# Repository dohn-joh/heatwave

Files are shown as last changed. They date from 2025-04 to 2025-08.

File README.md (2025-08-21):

cover_photo

***

Heatwave is a 36-key wireless, curved alpha stagger keyboard with integrated lever keycaps.

[PCB](pcb)

[Case files](case)

[swell keycaps](https://github.com/dohn-joh/swell-keycaps)

[ZMK Module](https://github.com/dohn-joh/heatwave-zmk-module)

[video](https://vimeo.com/1097657262)

***

## BOM
|Part|Quantity|Link|
|-|:-:|-|
|Microcontroller: Xiao nRF52840 Plus|1|https://www.seeedstudio.com/Seeed-Studio-XIAO-nRF52840-Plus-p-6359.html|
|Battery: 301230 with molex pico ezmate connector|1|Select L0040. https://www.aliexpress.us/item/3256802674181210.html|
|Battery connector: molex pico ezmate 1x02|1|Select 2P. https://www.aliexpress.us/item/3256805726980487.html|
|Reset button: EVQPUC02K|1|https://www.aliexpress.us/item/2251832616044011.html|
|Diodes: BAV70 (SOT-23)|18|https://www.amazon.com/dp/B079KKPMBT|
|M2 heatset inserts (OD:3.2, Height: 2-3mm)|6|https://www.aliexpress.us/item/3256806286387666.html|
|M2 screws 5mm, flat head|6|https://www.aliexpress.us/item/3256805084387535.html|
|Switches|36|Your choice of choc v2. Recommended: Lofree hades or any POM silent linear switch|
|Kailh Choc PG1350 Hot Swap Sockets|36|https://www.aliexpress.us/item/3256803687338432.html|
|Rubber feet 6mm diameter x 1mm height|6|Unfortunately this vendor only lists higher quantities now. If the price is too high, maybe try contacting the vendor for smaller quantities. https://www.aliexpress.com/store/1100976482|
|Keycaps|36|https://github.com/dohn-joh/swell-keycaps|
|Magnetic USB connector/cable: Netdot Gen10|1|https://www.amazon.com/dp/B07MBD3FZD|
|Steel dressmaker pins, Size 20 (1-1/4")|2|https://www.amazon.com/dp/B003W0TIH6|

## Build notes
Depending on the quality of the MJF prints:
- You will likely need to postprocess the lever keycaps in order for them to actuate properly. (This is by design. It is much easier to remove material than to add.) Postprocessing is very straightforward. All you need is a small strip of 80 grit sandpaper. Wet the sandpaper and lightly sand the underside of the lever keycap, then test to see if it actuates. If it does not, continue to sand and test until you get the desired thickness. If you want to be super accurate, you can use a caliper to measure the thickness after each sanding to match the thickness of both lever keycaps.
- If the dressmaker pin is not friction fitting, you can either glue the head in place, or carefully use a soldering iron to heatset it in place.

***








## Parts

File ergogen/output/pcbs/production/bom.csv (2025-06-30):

Designator | Footprint | Quantity | Value | LCSC Part #
D1, D10, D11, D12, D13, D14, D15, D16, D17, D18, D2, D3, D4, D5, D6, D7, D8, D9 | SOT-23 | 18
EC1 | pcb_shape | 1
H1, H2, H3, H4, H5, H6 | mounting_hole | 6
MCU1 | xiao_plus_smd_prod | 1
XX1 | sw_reset_side | 1
XX2 | conn_molex_pico_front | 1

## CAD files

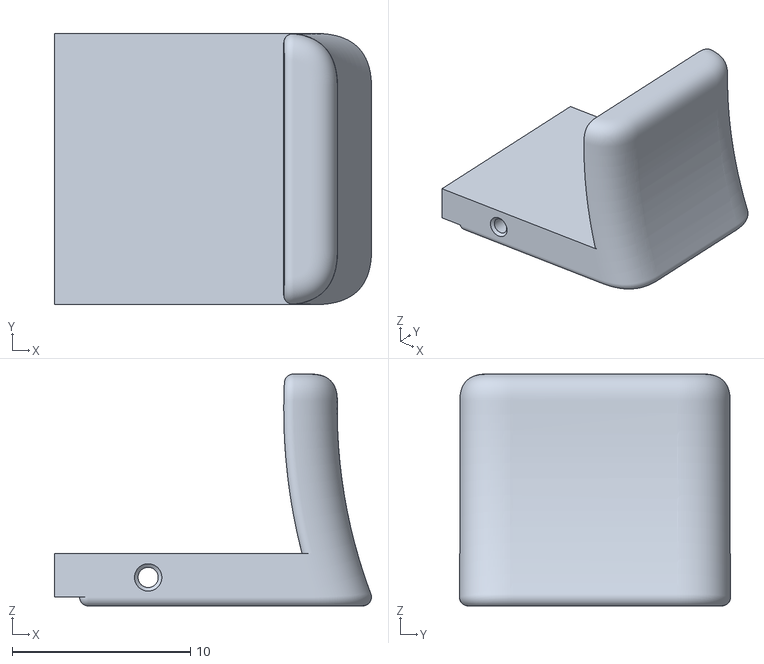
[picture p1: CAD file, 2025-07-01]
case/lever_keycap_1u.stl
17.8 x 15.2 x 13.0

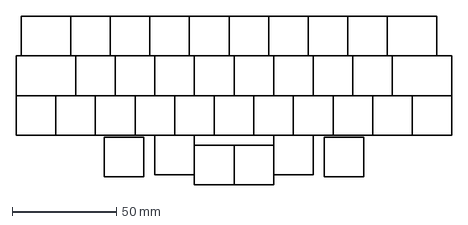
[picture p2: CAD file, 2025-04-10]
ergogen/output/points/demo.dxf
209.0 x 80.8 mm

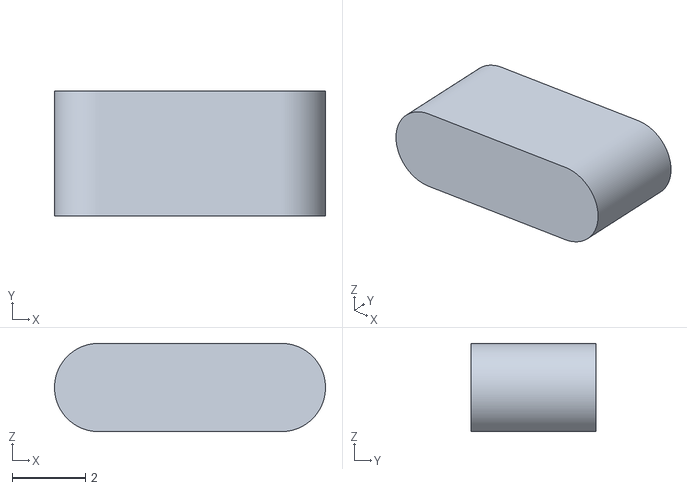
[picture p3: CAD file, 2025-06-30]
case/reset_button.stl
7.42 x 3.43 x 2.42

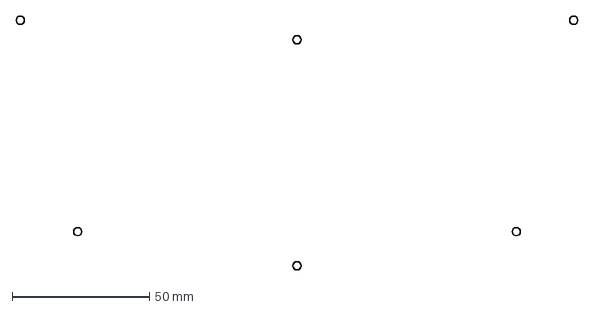
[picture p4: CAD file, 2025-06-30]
ergogen/output/outlines/threaded_inserts.dxf
204.8 x 92.5 mm

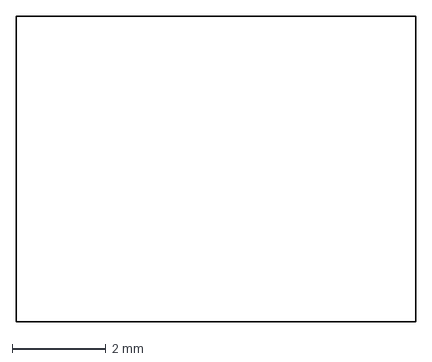
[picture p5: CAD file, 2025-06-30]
ergogen/output/outlines/reset_cutout.dxf
8.50 x 6.50 mm

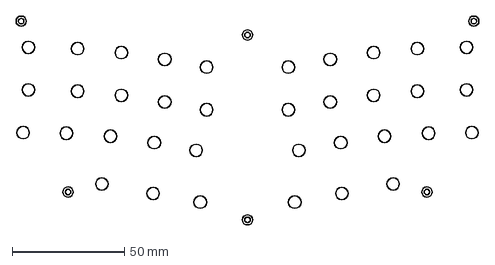
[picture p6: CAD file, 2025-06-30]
ergogen/output/outlines/case_bottom.dxf
206.3 x 93.1 mm

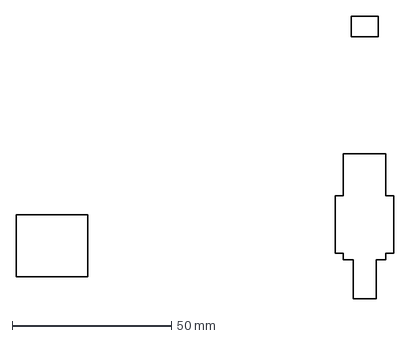
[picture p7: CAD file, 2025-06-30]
ergogen/output/outlines/case_cutouts.dxf
118.5 x 88.8 mm

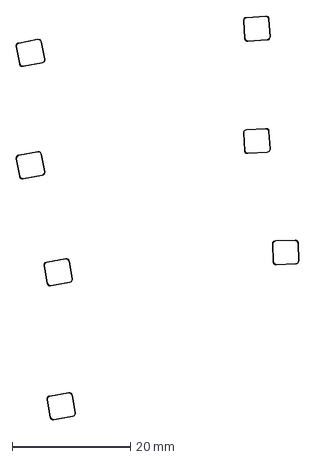
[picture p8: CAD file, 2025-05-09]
ergogen/output/outlines/diode_cutouts_mirror.dxf
47.8 x 68.3 mm

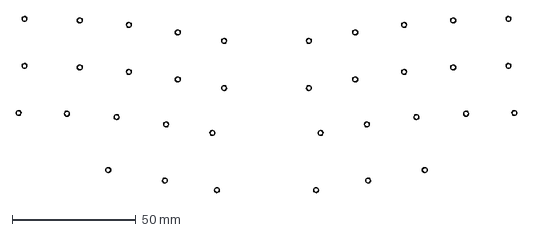
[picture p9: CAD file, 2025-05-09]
ergogen/output/outlines/hotswap_locations.dxf
202.0 x 71.1 mm

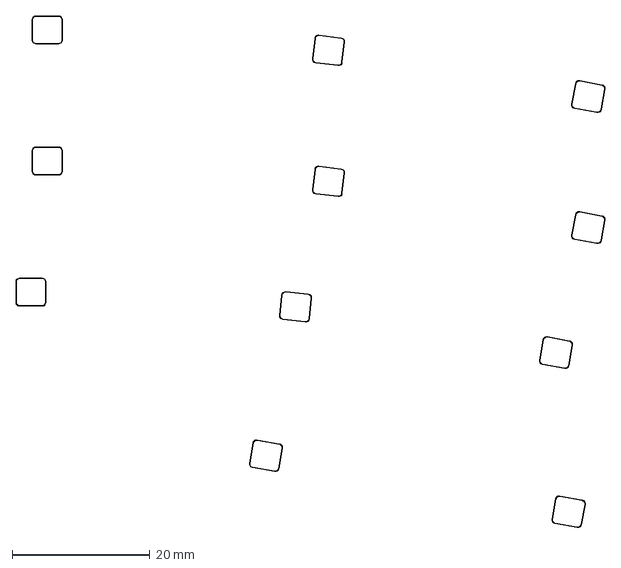
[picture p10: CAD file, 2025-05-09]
ergogen/output/outlines/diode_cutouts.dxf
85.4 x 74.2 mm

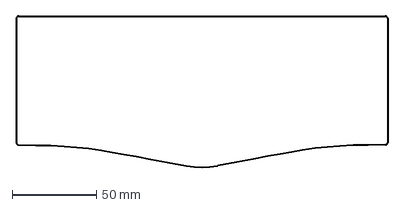
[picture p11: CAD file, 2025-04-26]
ergogen/output/outlines/pcb_shape.dxf
220.4 x 89.9 mm

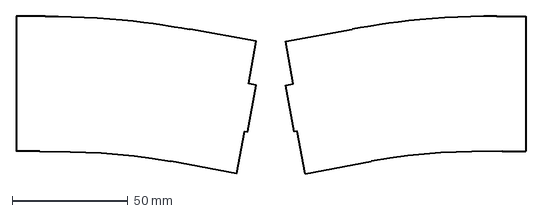
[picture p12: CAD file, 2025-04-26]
ergogen/output/outlines/keywalls.dxf
220.4 x 68.0 mm

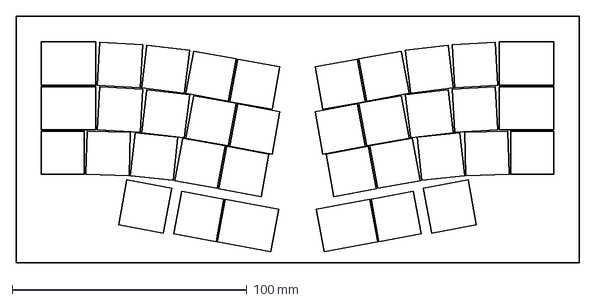
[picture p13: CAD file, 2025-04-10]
ergogen/output/outlines/preview.dxf
240.0 x 105.0 mm

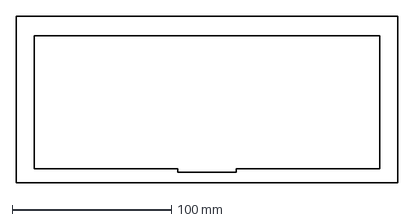
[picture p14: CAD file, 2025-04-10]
ergogen/output/outlines/case_top.dxf
240.0 x 105.0 mm

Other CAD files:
ergogen/output/outlines/choc_pin_cutouts.dxf
ergogen/output/outlines/switch_cutouts.dxf
ergogen/output/outlines/keycaps.dxf
ergogen/output/outlines/top_case_gap.dxf
ergogen/output/outlines/hotswap_cuts-F_SilkS.dxf
ergogen/output/outlines/key_walls.dxf
ergogen/output/outlines/pcb.dxf
ergogen/output/outlines/screw_heads.dxf
ergogen/output/outlines/screw_holes.dxf
ergogen/output/outlines/screws.dxf
ergogen/output/outlines/screws_heads.dxf
ergogen/output/outlines/screws_holes.dxf
ergogen/output/outlines/test.dxf
ergogen/output/outlines/top_case_outer.dxf
ergogen/output/pcbs/hotswap_cuts-F_SilkS.dxf

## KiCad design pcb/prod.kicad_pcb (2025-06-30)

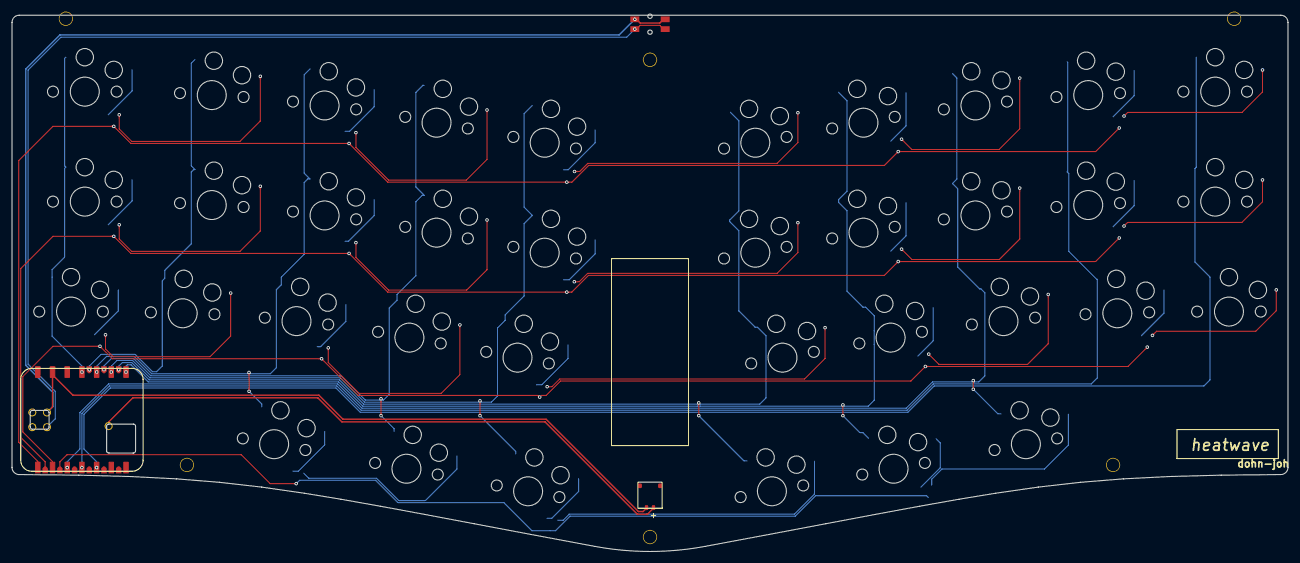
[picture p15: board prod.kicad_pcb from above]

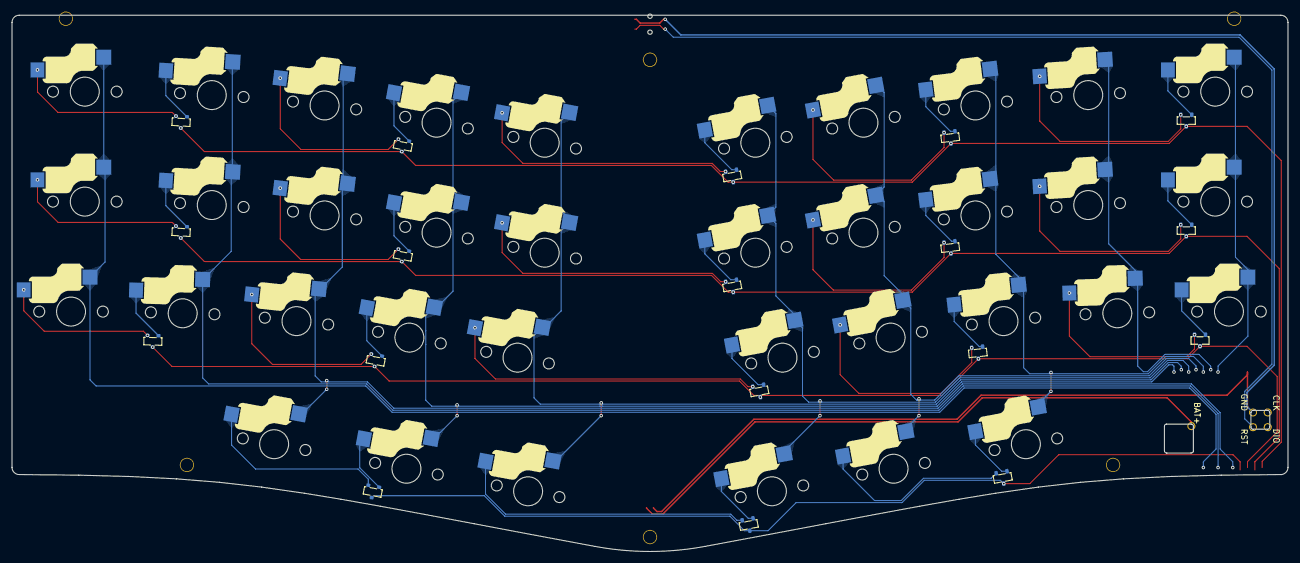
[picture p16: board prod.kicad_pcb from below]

Board: 2 copper layers, 220.4 x 92.6 mm, 64 parts (18 on the bottom side), 53 nets.

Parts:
D1, D2, D3, D4, D5, D6, D7, D8, D9, D10, D11, D12, D13, D14, D15, D16, D17, D18: SOT-23
EC1: pcb_shape
H1, H2, H3, H4, H5, H6: mounting_hole
MCU1: xiao_plus_smd_prod
SW1, SW2: choc
SW3, SW4, SW5, SW6, SW7, SW8, SW9, SW10, SW11, SW12, SW13, SW14, SW15, SW16, SW17, SW18, SW19, SW20, SW21, SW22, SW23, SW24, SW25, SW26, SW27, SW28, SW29, SW30: sw_choc_1u
SW31, SW32, SW33, SW34, SW35, SW36: sw_choc_1.25u
XX1: sw_reset_side
XX2: conn_molex_pico_front

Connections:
BAT+: MCU1.28, XX2.1
C1: MCU1.11, SW19.1, SW31.1, SW33.1
C2: MCU1.23, SW3.1, SW11.1, SW20.1
C3: MCU1.10, SW1.1, SW4.1, SW12.1, SW21.1
C4: MCU1.22, SW5.1, SW13.1, SW22.1, SW29.1
C5: MCU1.9, SW6.1, SW14.1, SW23.1, SW35.1
C6: MCU1.21, SW10.1, SW18.1, SW28.1, SW36.1
C7: MCU1.8, SW9.1, SW17.1, SW27.1, SW30.1
C8: MCU1.3, SW2.1, SW8.1, SW16.1, SW26.1
C9: MCU1.4, SW7.1, SW15.1, SW25.1
C10: MCU1.5, SW24.1, SW32.1, SW34.1
GND: MCU1.13, MCU1.27, XX1.1, XX1.3, XX2.2
R1: D1.3, D2.3, D3.3, D12.3, D13.3, MCU1.1
R2: D4.3, D5.3, D6.3, D14.3, D15.3, MCU1.15
R3: D7.3, D8.3, D9.3, D16.3, D17.3, MCU1.2
R4: D10.3, D11.3, D18.3, MCU1.16
RST: MCU1.26, XX1.2, XX1.4
a_home: D4.1, SW33.2
b_bottom: D9.1, SW23.2
base_thumb: D10.2, SW29.2
c_bottom: D8.1, SW21.2
d_home: D5.1, SW12.2
e_top: D2.1, SW4.2
ext_thumb: D11.1, SW35.2
f_home: D5.2, SW13.2
flex_thumb: D10.1, SW1.2
g_home: D6.1, SW14.2
mirror_a_home: D14.2, SW34.2
mirror_b_bottom: D9.2, SW28.2
mirror_base_thumb: D18.1, SW30.2
mirror_c_bottom: D17.2, SW26.2
mirror_d_home: D15.2, SW16.2
mirror_e_top: D13.2, SW8.2
mirror_ext_thumb: D11.2, SW36.2
mirror_f_home: D15.1, SW17.2
mirror_flex_thumb: D18.2, SW2.2
mirror_g_home: D6.2, SW18.2
mirror_q_top: D12.2, SW32.2
mirror_r_top: D13.1, SW9.2
mirror_s_home: D14.1, SW15.2
mirror_t_top: D3.2, SW10.2
mirror_v_bottom: D17.1, SW27.2
mirror_w_top: D12.1, SW7.2
mirror_x_bottom: D16.1, SW25.2
mirror_z_bottom: D16.2, SW24.2
q_top: D1.1, SW31.2
r_top: D2.2, SW5.2
s_home: D4.2, SW11.2
t_top: D3.1, SW6.2
v_bottom: D8.2, SW22.2
w_top: D1.2, SW3.2
x_bottom: D7.2, SW20.2
z_bottom: D7.1, SW19.2

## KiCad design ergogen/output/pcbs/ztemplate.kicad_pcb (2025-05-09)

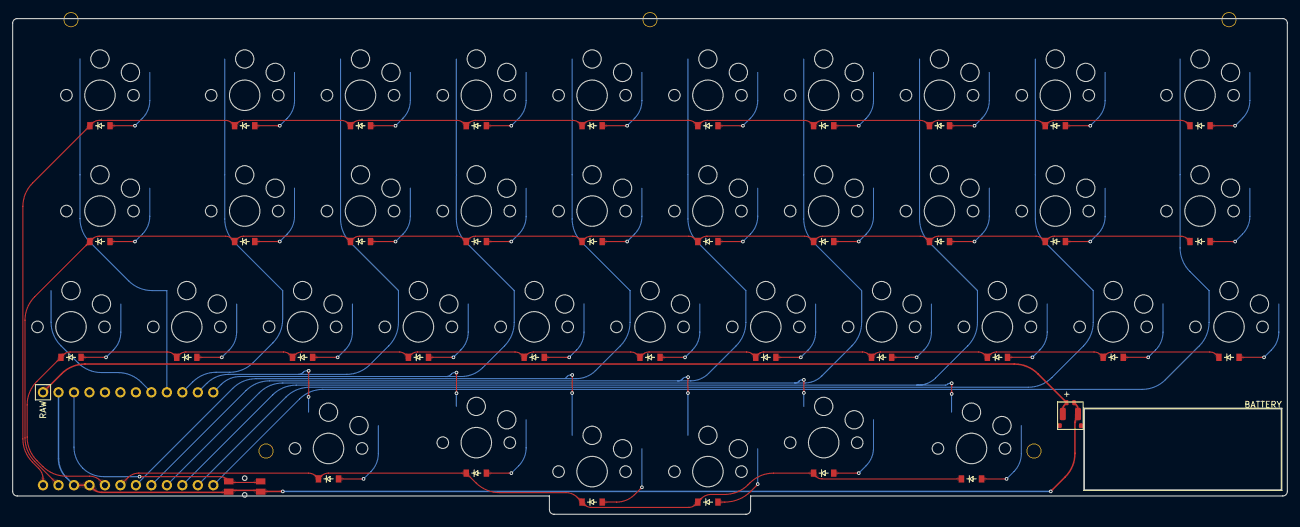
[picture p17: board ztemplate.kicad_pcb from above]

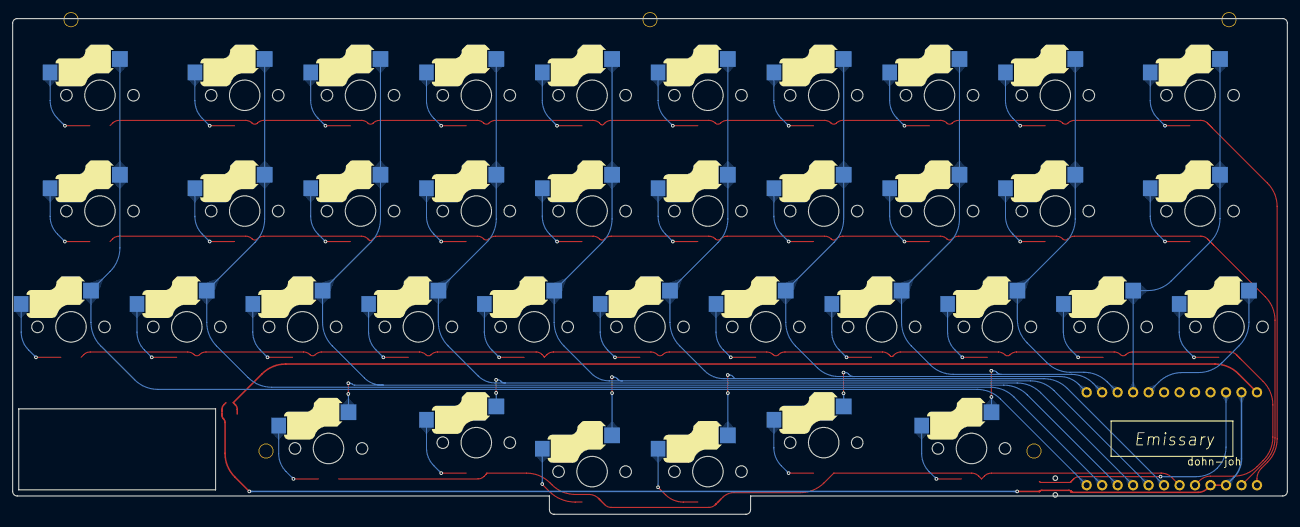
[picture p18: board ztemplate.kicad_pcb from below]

Board: 2 copper layers, 209.2 x 81.3 mm, 83 parts (37 on the bottom side), 55 nets.

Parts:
CONN1: conn_molex_pico_front
D1, D2, D3, D4, D5, D6, D7, D8, D9, D10, D11, D12, D13, D14, D15, D16, D17, D18, D19, D20, D21, D22, D23, D24, D25, D26, D27, D28, D29, D30, D31, D32, D33, D34, D35, D36, D37: ComboDiode
H1, H2, H3, H4, H5: mounting_hole
MCU1: supermini_front
PAD1: battery_pads
S1, S2, S3, S4, S5, S6, S7, S8, S9, S10, S11, S12, S13, S14, S15, S16, S17, S18, S19, S20, S21, S22, S23, S24, S25, S26, S27, S28, S29, S30, S31, S32, S33, S34, S35, S36, S37: switch_choc_v1_v2_filled
SW1: reset_button; sw_reset_side

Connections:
C0: MCU1.8, S21.1
C1: MCU1.9, S1.1, S11.1, S22.1
C2: MCU1.10, S2.1, S12.1, S23.1
C3: MCU1.11, S3.1, S13.1, S24.1, S32.1
C4: MCU1.12, S4.1, S14.1, S25.1, S33.1
C5: MCU1.18, S5.1, S15.1, S26.1, S34.1
C6: MCU1.17, S6.1, S16.1, S27.1, S35.1
C7: MCU1.16, S7.1, S17.1, S28.1, S36.1
C8: MCU1.15, S8.1, S18.1, S29.1, S37.1
C9: MCU1.14, S9.1, S19.1, S30.1
C10: MCU1.13, S10.1, S20.1, S31.1
GND: CONN1.2, MCU1.2, MCU1.21, MCU1.22, PAD1.2, SW1.1, SW1.3
R1: D1.1, D2.1, D3.1, D4.1, D5.1, D6.1, D7.1, D8.1, D9.1, D10.1, MCU1.24
R2: D11.1, D12.1, D13.1, D14.1, D15.1, D16.1, D17.1, D18.1, D19.1, D20.1, MCU1.23
R3: D21.1, D22.1, D23.1, D24.1, D25.1, D26.1, D27.1, D28.1, D29.1, D30.1, D31.1, MCU1.20
R4: D32.1, D33.1, D34.1, D35.1, D36.1, D37.1, MCU1.19
RAW: CONN1.1, MCU1.1, PAD1.1
RST: MCU1.3, SW1.2, SW1.4
a_home: D11.2, S11.2
b_bottom: D26.2, S26.2
base2_thumb: D36.2, S36.2
base_thumb: D33.2, S33.2
c_bottom: D24.2, S24.2
comma_bottom: D29.2, S29.2
d_home: D13.2, S13.2
dot_bottom: D30.2, S30.2
e_top: D3.2, S3.2
ext2_thumb: D35.2, S35.2
ext_thumb: D34.2, S34.2
extra_bottom: D21.2, S21.2
f_home: D14.2, S14.2
flex2_thumb: D37.2, S37.2
flex_thumb: D32.2, S32.2
g_home: D15.2, S15.2
h_home: D16.2, S16.2
i_top: D8.2, S8.2
j_home: D17.2, S17.2
k_home: D18.2, S18.2
l_home: D19.2, S19.2
m_bottom: D28.2, S28.2
n_bottom: D27.2, S27.2
o_top: D9.2, S9.2
p_top: D10.2, S10.2
q_top: D1.2, S1.2
r_top: D4.2, S4.2
s_home: D12.2, S12.2
semi_home: D20.2, S20.2
slash_bottom: D31.2, S31.2
t_top: D5.2, S5.2
u_top: D7.2, S7.2
v_bottom: D25.2, S25.2
w_top: D2.2, S2.2
x_bottom: D23.2, S23.2
y_top: D6.2, S6.2
z_bottom: D22.2, S22.2

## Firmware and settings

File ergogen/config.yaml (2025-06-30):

units:
  $default_width: u # u = 19mm
  $default_height: u
  angle: 0
  angle_key: 3.5
  split: u+30 # goal is to have ~ 100mm between homing keys
  capxy: 18.4 # 1u dimensions are 18.4x18.4
  gap: 0.6 # gap between keycaps (19-18.4)
  thumb_offset: 2u
  switch_xy_mx: 14 # switch hole
  switch_xy_choc: 13.75
  dcx: 3.3+1
  dcy: 3+1
  lxy: 19.5
  # sf: 19.151 # sf=19.151 combined with hotswap outer_pad_width=2.4 gets hotswap pad right up against pcb edge without DRC error.
  sf: 22 # testing
  ## supermini dimensions
  # mcux: 18.1 # with 0.1mm tolerance for fr4 variance
  # mcuy: 33.85 # length from usb to end of pcb
  ## xiao plus PCB footprint dimensions. does not include USB!
  mcux: 21.135
  mcuy: 18.542
  # space between keycap and case wall
  wallxy: 1
  min_wall_thickness: 0.7

  # 301230 battery dimensions
  bcx: 12.5+0.8
  bcy: 31.5+0.8

  # reset switch dimensions
  rsx: 6.8
  rsy: 3.5
  rsh: 0.75 # hole diameter
  rsd: 2.75 # distance between holes
  rcx: 8.5 # reset switch cutout. don't forget to account for solder pads/blobs
  rcy: rsy+3 # reset switch cutout

  # screw hole diameter (M2)
  # screw head diameter ~3.3
  # M2 nut height ~1.5
  scd: 2.2
  # threaded insert diameter
  tid: 3
  # screw hole diameter for case bottom
  scb: 2.45
  # screwhead diameter
  sch: 4.5

  # DON'T BOTHER TRYING TO MAKE OFFSETS USING EXPAND UNLESS THE PCB IS PERFECTLY RECTANGULAR. ANY OTHER SHAPES WILL NOT WORK.
  case_offset: 0.5 # PLA: experimented with .25mm. bad fit. it's not worth trying to tighten up this tolerance.
  case_thickness: 5 # PLA: 1.5mm results in warped walls. can reduce if you want to print in different material.
  # DON'T fillet the inner corners of the case. makes tolerances more difficult to dial in with PLA. just keep square corners.

  # offsets from key_walls
  top_offset: 6.5 # measured: 0.775u; ~14.7mm
  bottom_offset: 1 # measured 0.61u; ~11.6mm
  side_offset: 3.5 # measured 0.44u; ~8.4mm

points:
  zones:
    r1:
      anchor:
        rotate: -angle/2
      mirror:
        ref: r1_t_top
        shift: [0.5u, 0.5u]
        distance: 0.75u
      key:
        width: u
        height: u
        autobind: 0
        tags: alphas
        column_next: "this is a bug!"
        column_prev: "this is a bug!"
      rows.top:
        row_net: R1
      columns:
        q:
          key:
            width: 1.25u
            column_net: C1
            column_next: w
            mirror.column_net: C10
            tags: [alphas, twofive, odd]
        w:
          key:
            spread: 1.25u/2+u/2
            origin: [-0.5u, -0.5u]
            splay: -angle_key
            column_net: C2
            mirror.column_net: C9
            column_prev: mirror_q
            tags: [alphas, even]
        e:
          key:
            origin: [-0.5u, -0.5u]
            splay: -angle_key
            column_net: C3
            mirror.column_net: C8
            column_next: r
            tags: [alphas, odd]
        r:
          key:
            origin: [-0.5u, -0.5u]
            splay: -angle_key
            column_net: C4
            mirror.column_net: C7
            column_prev: mirror_e
            tags: [alphas, even]
        t:
          key:
            column_net: C5
            mirror.column_net: C6
            column_next: mirror_t
            tags: [alphas, odd]
    r2:
      anchor:
        ref: r1_q_top
        shift: [0, -u]
      mirror:
        ref.aggregate.parts: [r1_q_top, mirror_r1_q_top]
      key:
        width: u
        height: u
        autobind: 0
        tags: alphas
      rows.home:
        row_net: R2
      columns:
        a:
          key:
            width: 1.25u
            column_net: C1
            mirror.column_net: C10
            column_next: s
            tags: [alphas, twofive, odd]
        s:
          key:
            spread: 1.25u/2 + u/2
            origin: [-0.5u, -0.5u]
            splay: -angle_key
            column_net: C2
            mirror.column_net: C9
            column_prev: mirror_a
            tags: [alphas, even]
        d:
          key:
            origin: [-0.5u, -0.5u]
            splay: -angle_key
            column_net: C3
            mirror.column_net: C8
            column_next: f
            tags: [alphas, odd]
        f:
          key:
            origin: [-0.5u, -0.5u]
            splay: -angle_key
            column_net: C4
            mirror.column_net: C7
            column_prev: mirror_d
            tags: [alphas, even]
        g:
          key:
            column_net: C5
            mirror.column_net: C6
            column_next: mirror_g
            tags: [alphas, odd]
    r3:
      anchor:
        ref: r1_q_top
        shift: [-1.25u/2+u/2, -2u]
      mirror:
        ref.aggregate.parts: [r1_q_top, mirror_r1_q_top]
      key:
        width: u
        height: u
        autobind: 0
        tags: alphas
      rows.bottom:
        row_net: R3
      columns:
        z:
          key:
            width: u
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

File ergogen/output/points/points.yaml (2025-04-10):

r1_q_top:
    x: 0
    'y': 0
    r: 0
    meta:
        stagger: 0
        spread: 19
        splay: 0
        origin:
            - 0
            - 0
        orient: 0
        shift:
            - 0
            - 0
        rotate: 0
        adjust: {}
        width: 23.75
        height: 19
        padding: 19
        autobind: 0
        skip: false
        asym: both
        colrow: q_top
        name: r1_q_top
        tags:
            - alphas
            - twofive
        bind:
            - 0
            - 4u
            - 2u
            - 0
        column_net: C1
        row_net: R1
        zone:
            key:
                width: u
                height: u
                autobind: 0
                tags: alphas
            rows:
                top:
                    row_net: R1
            columns:
                q:
                    key:
                        bind:
                            - 0
                            - 4u
                            - 2u
                            - 0
                        width: 1.25u
                        column_net: C1
                        tags:
                            - alphas
                            - twofive
                    rows: {}
                    name: q
                w:
                    key:
                        spread: 1.25u/2+u/2
                        column_net: C2
                    rows: {}
                    name: w
                e:
                    key:
                        column_net: C3
                    rows: {}
                    name: e
                r:
                    key:
                        column_net: C4
                    rows: {}
                    name: r
                t:
                    key:
                        column_net: C5
                    rows: {}
                    name: t
            name: r1
        col:
            key:
                bind:
                    - 0
                    - 4u
                    - 2u
                    - 0
                width: 1.25u
                column_net: C1
                tags:
                    - alphas
                    - twofive
            rows: {}
            name: q
        row: top
        mirrored: false
r1_w_top:
    x: 21.375
    'y': 0
    r: 0
    meta:
        stagger: 0
        spread: 21.375
        splay: 0
        origin:
            - 0
            - 0
        orient: 0
        shift:
            - 0
            - 0
        rotate: 0
        adjust: {}
        width: 19
        height: 19
        padding: 19
        autobind: 0
        skip: false
        asym: both
        colrow: w_top
        name: r1_w_top
        tags: alphas
        column_net: C2
        row_net: R1
        zone:
            key:
                width: u
                height: u
                autobind: 0
                tags: alphas
            rows:
                top:
                    row_net: R1
            columns:
                q:
                    key:
                        bind:
                            - 0
                            - 4u
                            - 2u
                            - 0
                        width: 1.25u
                        column_net: C1
                        tags:
                            - alphas
                            - twofive
                    rows: {}
                    name: q
                w:
                    key:
                        spread: 1.25u/2+u/2
                        column_net: C2
                    rows: {}
                    name: w
                e:
                    key:
                        column_net: C3
                    rows: {}
                    name: e
                r:
                    key:
                        column_net: C4
                    rows: {}
                    name: r
                t:
                    key:
                        column_net: C5
                    rows: {}
                    name: t
            name: r1
        col:
            key:
                spread: 1.25u/2+u/2
                column_net: C2
            rows: {}
            name: w
        row: top
        mirrored: false
r1_e_top:
    x: 40.375
    'y': 0
    r: 0
    meta:
        stagger: 0
        spread: 19
        splay: 0
        origin:
            - 0
            - 0
        orient: 0
        shift:
            - 0
            - 0
        rotate: 0
        adjust: {}
        width: 19
        height: 19
        padding: 19
        autobind: 0
        skip: false
        asym: both
        colrow: e_top
        name: r1_e_top
        tags: alphas
        column_net: C3
        row_net: R1
        zone:
            key:
                width: u
                height: u
                autobind: 0
                tags: alphas
            rows:
                top:
                    row_net: R1
            columns:
                q:
                    key:
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

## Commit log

2025-04-10 fixed xiao arcs in ergogen fp
    [backup.kicad_pcb, case_bottom.dxf, case_cutouts.dxf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]
2025-04-26 updated footprint models
    [case_bottom.dxf, case_cutouts.dxf, keywalls.dxf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]
2025-04-29 update file name
    [heatwave.kicad_pcb, motive.kicad_pcb, render.kicad_pcb]
2025-07-01 added lever keycap
    [lever_keycap_1u.stl]
2025-07-01 copy kicad pcb to pcb folder
    [prod.kicad_pcb]
2025-07-21 add BOM
2025-08-21 add didoes to BOM
